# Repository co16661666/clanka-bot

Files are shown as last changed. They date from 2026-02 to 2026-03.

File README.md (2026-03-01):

# ⏰ deska clanka

An interactive, character-driven smart alarm clock built with the **Seeed Studio XIAO ESP32C3**. This project brings a standard clock to life using procedural OLED eye animations and coordinated servo-driven arms to express different moods based on the time of day or user interaction.

## ✨ Features
* **Procedural Eye Animations:** Uses geometric masking on an SSD1306 OLED to create smooth, expressive eyes without consuming excess memory with image files.
* **Coordinated Arm Movements:** Two micro-servos act as arms that react alongside the facial expressions.
* **Dynamic Moods:** Transitions seamlessly between states like Happy, Tired, Sleepy, Stretching, and an active Alarm sequence.
* **Custom Enclosure:** Physical housing and mounting brackets designed entirely in Solidworks.

---

## 🛠️ Hardware & CAD Design (Per Module)
* **Microcontroller:** [Seeed Studio XIAO ESP32C3](https://www.seeedstudio.com/Seeed-XIAO-ESP32C3-p-5431.html)
* **Display:** 0.96" I2C OLED Display (SSD1306)
* **Actuators:** 2x Micro Servos (e.g., SG90)
* **Power:** 3.3V supply (via power bank)

### Mechanical Design
The physical enclosure and servo mounts were modeled using **Solidworks**. 
* The CAD files (including native `.SLDPRT`/`.SLDASM` and `.STL` files for 3D printing, which are not included here) can be found in the `/housing` directory of this repository. Previous versions of the arm are still in the repository, with V2 files being the most up to date.
* The Arduino files were .ino and relate to the `/expressions-programV2` and `/brain-program` files in the repository.

---

## ⚙️ Setup and Installation

### 1. Wiring Guide
Ensure your components are wired exactly as follows before connecting power:

| Component | Pin Name | XIAO Pin (Label) | ESP32 GPIO |
| :--- | :--- | :--- | :--- |
| **OLED SDA** | SDA | D4 | GPIO 6 |
| **OLED SCL** | SCL | D5 | GPIO 7 |
| **Left Arm Servo** | Signal | D0 | GPIO 2 |
| **Right Arm Servo** | Signal | D1 | GPIO 3 |
| **All Components** | VCC | 3V3 | - |
| **All Components** | GND | GND | - |

### 2. Software Installation
This project is programmed using the Arduino IDE.
1. Download and install the [Arduino IDE](https://www.arduino.cc/en/software).
2. Add ESP32 Support: 
   * Go to **File > Preferences**.
   * Add `https://espressif.github.io/arduino-esp32/package_esp32_index.json` to the **Additional Boards Manager URLs**.
   * Go to **Tools > Board > Boards Manager**, search for `esp32` by Espressif Systems, and install it (Version 3.0.0 or higher required).
3. Select your board: Go to **Tools > Board > esp32** and select **XIAO_ESP32C3**.

### 3. Required Libraries
Open the Arduino Library Manager (**Sketch > Include Library > Manage Libraries...**) and install the following:
* `Adafruit_GFX` by Adafruit
* `Adafruit_SSD1306` by Adafruit
* `ESP32Servo` by Kevin Harrington (Standard `Servo.h` will not work on the ESP32 chip).

### 4. Uploading the Code
1. Connect the XIAO ESP32C3 to your computer via USB-C.
2. Select the correct COM port under **Tools > Port**.
3. Open the `expressions-programV2.ino` sketch.
4. Click the **Upload** arrow.

---

## 🤝 Attributions & Acknowledgments
This project was made possible by several excellent open-source tools, libraries, and community inspirations:
* **Adafruit Industries:** For the `Adafruit_GFX` and `Adafruit_SSD1306` libraries that drive the OLED display.
* **Kevin Harrington:** For the `ESP32Servo` library, allowing standard PWM servo control on the ESP32 architecture.
* **Espressif Systems & Seeed Studio:** For the ESP32 core board definitions and the XIAO hardware.
* **Design Inspiration:** The procedural masking logic for the eye expressions was heavily inspired by the "Vinny" robot eye designs and various open-source animated OLED eye projects found across the maker community. 
* **Solidworks:** Used for all 3D mechanical design, part modeling, and assembly testing.
* **AI & LLM policy:** Used to generate only code and execute ideas we had as a team.

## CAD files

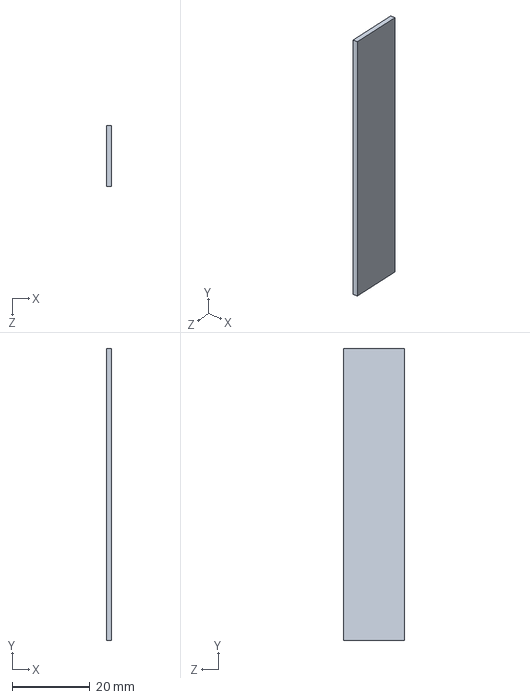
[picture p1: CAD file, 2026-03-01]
bot1/housing/solidwork_files/clanka_Arm1V2.SLDPRT
1.40 x 75.0 x 15.6 mm

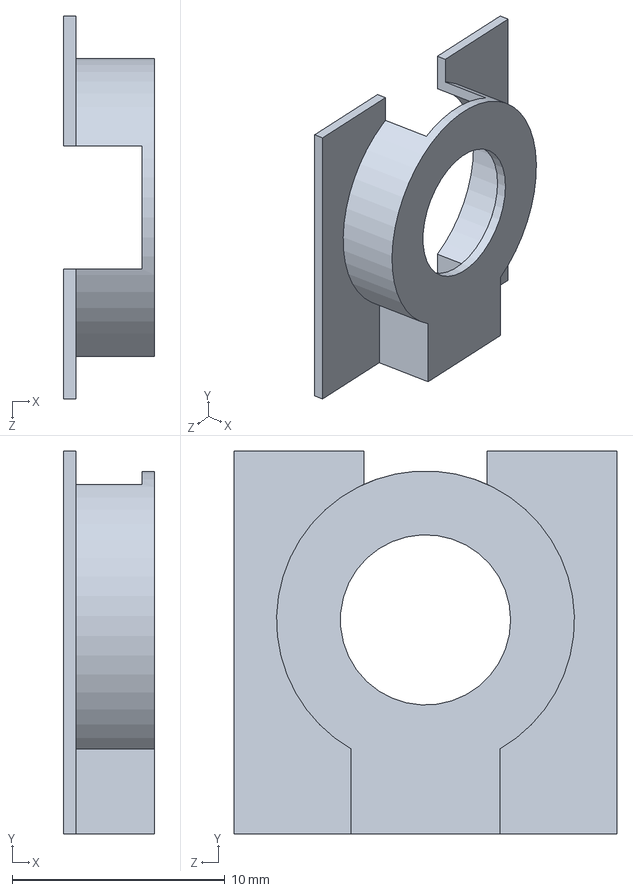
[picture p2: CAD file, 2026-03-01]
bot1/housing/solidwork_files/clankaBotArm_CasingV1.SLDPRT
4.30 x 18.0 x 18.0 mm

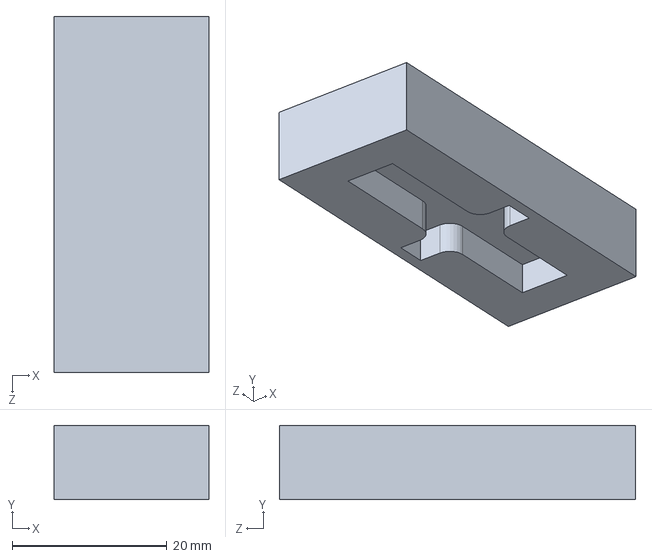
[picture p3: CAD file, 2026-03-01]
bot1/housing/solidwork_files/Arm_Connector_ClankaBotV2.SLDPRT
20.0 x 9.60 x 46.0 mm

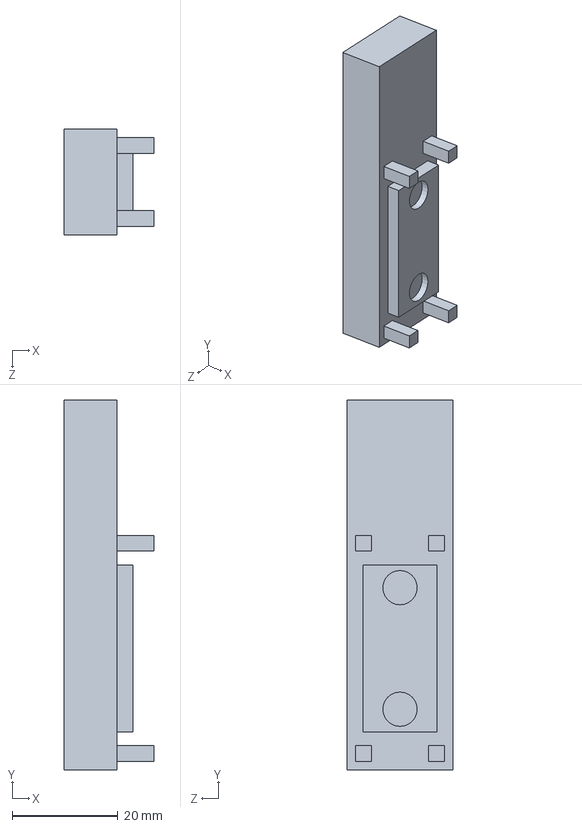
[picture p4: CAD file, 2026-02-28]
bot1/housing/solidwork_files/clanka_Arm1.SLDPRT
17.0 x 70.0 x 20.0 mm

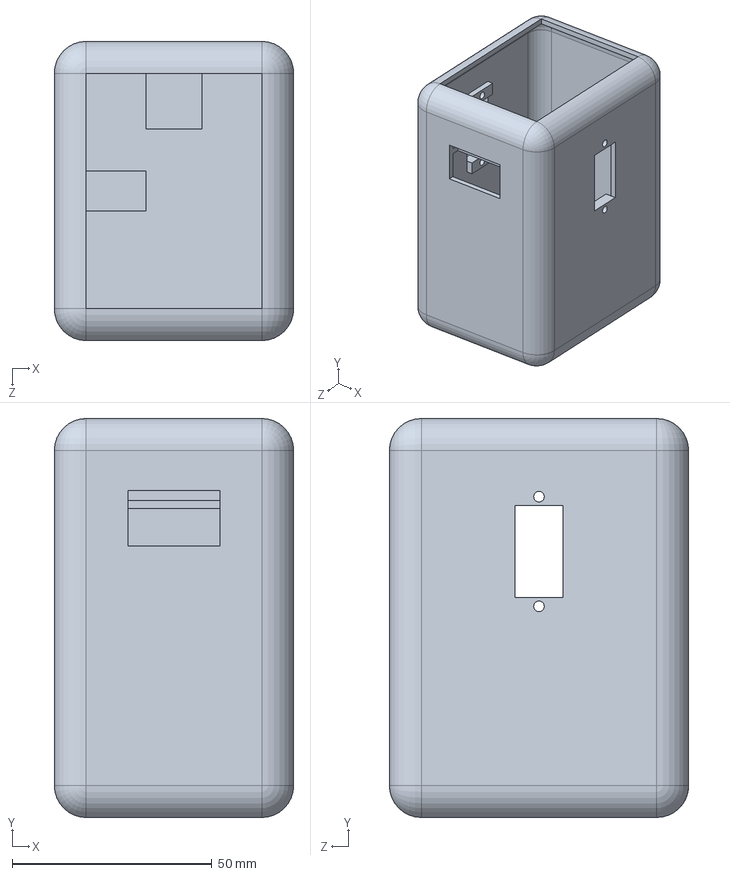
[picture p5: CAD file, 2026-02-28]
bot1/housing/solidwork_files/clanka_body.SLDPRT
60.0 x 100.0 x 75.0 mm

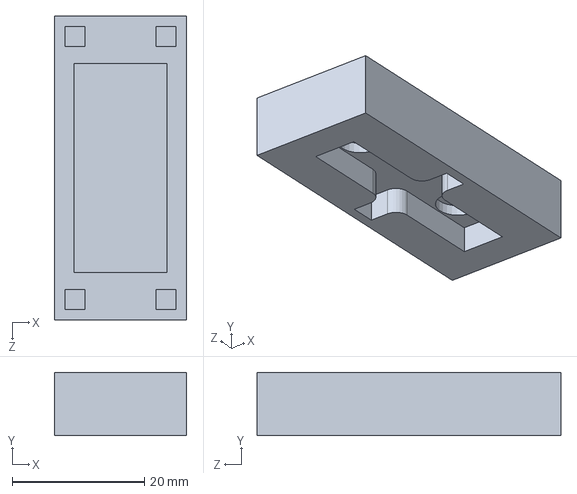
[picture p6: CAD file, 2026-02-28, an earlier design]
bot1/housing/solidwork_files/Arm_Connector_ClankaBotV1.SLDPRT
20.0 x 9.60 x 46.0 mm

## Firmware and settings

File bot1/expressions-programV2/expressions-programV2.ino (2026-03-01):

v#include <Wire.h>
#include <Adafruit_GFX.h>
#include <Adafruit_SSD1306.h>
#include <ESP32Servo.h> // Make sure to install "ESP32Servo" in the Library Manager!

// --- OLED SETTINGS ---
#define SCREEN_WIDTH 128
#define SCREEN_HEIGHT 64
#define OLED_RESET    -1 
Adafruit_SSD1306 display(SCREEN_WIDTH, SCREEN_HEIGHT, &Wire, OLED_RESET);

// XIAO ESP32C3 I2C Pins
#define I2C_SDA 6 
#define I2C_SCL 7 

// --- SERVO SETTINGS ---
Servo leftArm;
Servo rightArm;

// XIAO ESP32C3 Pins for Servos (D0 and D1)
const int leftArmPin = 2;  // Physical GPIO 2 corresponds to D0
const int rightArmPin = 3; // Physical GPIO 3 corresponds to D1

// --- MASTER EYE DRAWING FUNCTION ---
void drawVinnyEyes(int topEyelid, int bottomEyelid, int lookX) {
  display.clearDisplay();
  
  int eyeW = 24;
  int eyeH = 40;
  int leftX = 26;
  int rightX = 78; 
  int baseY = 12;

  // Draw the wide-open white eyes, shifted by lookX
  display.fillRoundRect(leftX + lookX, baseY, eyeW, eyeH, 8, SSD1306_WHITE);
  display.fillRoundRect(rightX + lookX, baseY, eyeW, eyeH, 8, SSD1306_WHITE);

  // Draw the Top Eyelid (Black box covering the top)
  if (topEyelid > 0) {
    display.fillRect(0, 0, 128, baseY + topEyelid, SSD1306_BLACK);
  }

  // Draw the Bottom Eyelid (Black box covering the bottom)
  if (bottomEyelid > 0) {
    display.fillRect(0, baseY + eyeH - bottomEyelid, 128, bottomEyelid + 15, SSD1306_BLACK);
  }

  display.display();
}

// ==========================================
// --- COMBINED MOOD FUNCTIONS ---
// ==========================================

void moodHappy() {
  drawVinnyEyes(0, 20, 0); // Joyful squint
  leftArm.write(90);       // Arms neutral
  rightArm.write(90);
}

void moodTired() {
  drawVinnyEyes(20, 0, 0); // Heavy top eyelids
  leftArm.write(45);       // Arms drooping down
  rightArm.write(135); 
}

void moodSleepy() {
  drawVinnyEyes(30, 0, 0); // Almost closed eyes
  leftArm.write(10);       // Arms fully resting
  rightArm.write(170); 
}

void moodSnoring() {
  drawVinnyEyes(18, 18, 0); // Squished flat lines
  
  // Add floating 'Zzz'
  display.setTextSize(1);
  display.setTextColor(SSD1306_WHITE);
  display.setCursor(55, 0);
  display.print("Z");
  display.setCursor(65, 8);
  display.print("z");
  display.display();
  
  leftArm.write(10);       // Arms resting
  rightArm.write(170);
}

void moodStretching() {
  // Eyes look left, arms go up
  drawVinnyEyes(0, 0, -8); 
  leftArm.write(150);  
  rightArm.write(30);  
  delay(600);
  
  // Eyes look right, arms wiggle
  drawVinnyEyes(0, 0, 8);  
  leftArm.write(120);
  rightArm.write(60);
  delay(300);
  
  // Eyes center, stretch finishes
  drawVinnyEyes(0, 0, 0);
  leftArm.write(150);
  rightArm.write(30);
  delay(600);
}

void moodAlarm() {
  // Wide open eyes, frantic arms
  drawVinnyEyes(0, 0, 0);
  leftArm.write(180);
  rightArm.write(0);
  
  display.invertDisplay(true); // Flash screen white
  delay(150);
  
  leftArm.write(0);
  rightArm.write(180);
  
  display.invertDisplay(false); // Flash screen back to normal
  delay(150);
}

// ==========================================
// --- REQUIRED ARDUINO FUNCTIONS ---
// ==========================================

void setup() {
  Serial.begin(115200);

  // 1. Setup Servos
  // We use ESP32Servo library standard attach
  leftArm.attach(leftArmPin);
  rightArm.attach(rightArmPin);

  // 2. Setup OLED with custom XIAO pins
  Wire.begin(I2C_SDA, I2C_SCL);
  if(!display.begin(SSD1306_SWITCHCAPVCC, 0x3C)) { 
    Serial.println(F("SSD1306 allocation failed"));
    for(;;); // Loop forever if display fails
  }
  
  display.clearDisplay();
  display.display();
}

void loop() {
  // A simple test sequence to cycle through all your moods!
  
  moodHappy();
  delay(3000);
  
  moodTired();
  delay(3000);
  
  moodSleepy();
  delay(3000);
  
  moodSnoring();
  delay(3000);
  
  moodStretching();
  delay(1000);
  
  // Flash the alarm a few times
  for(int i = 0; i < 10; i++) {
    moodAlarm();
  }
}

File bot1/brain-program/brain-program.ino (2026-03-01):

#include "arduino_secrets.h"
#include <WiFiClientSecure.h>
#include <MQTTClient.h>
#include <ArduinoJson.h>
#include "WiFi.h"
#include "vinny_moods.h"

// The MQTT topics that this device should publish/subscribe
#define AWS_IOT_PUBLISH_TOPIC   "esp32/pub"
#define AWS_IOT_SUBSCRIBE_TOPIC "esp32/sub"

WiFiClientSecure net = WiFiClientSecure();
MQTTClient client = MQTTClient(256);

void connectAWS()
{
  WiFi.mode(WIFI_STA);
  WiFi.begin(WIFI_SSID, WIFI_PASSWORD);

  Serial.println("Connecting to Wi-Fi");

  while (WiFi.status() != WL_CONNECTED){
    delay(500);
    Serial.print(".");
  }

  // Configure WiFiClientSecure to use the AWS IoT device credentials
  net.setCACert(AWS_CERT_CA);
  net.setCertificate(AWS_CERT_CRT);
  net.setPrivateKey(AWS_CERT_PRIVATE);

  // Connect to the MQTT broker on the AWS endpoint we defined earlier
  client.begin(AWS_IOT_ENDPOINT, 8883, net);

  // Create a message handler
  client.onMessage(messageHandler);

  Serial.print("Connecting to AWS IOT");
  
  while (!client.connect(THINGNAME)) {
    Serial.print(".");
    
    // Print diagnostic information
    Serial.println();
    Serial.print("MQTT Error Code: ");
    Serial.println(client.lastError());
    Serial.print("MQTT Return Code: ");
    Serial.println(client.returnCode());
    
    delay(1000);
  }

  if(!client.connected()){
    Serial.println("AWS IoT Timeout!");
    return;
  }

  // Subscribe to a topic
  client.subscribe(AWS_IOT_SUBSCRIBE_TOPIC);

  Serial.println("AWS IoT Connected!");
}

void publishMessage()
{
  StaticJsonDocument<200> doc;
  doc["time"] = millis();
  doc["sensor_a0"] = analogRead(0);
  char jsonBuffer[512];
  serializeJson(doc, jsonBuffer); // print to client

  if (client.publish(AWS_IOT_PUBLISH_TOPIC, jsonBuffer)) {
    Serial.println("Publish Success");
  } else {
    Serial.println("Publish Failed");
  }
}

void messageHandler(String &topic, String &payload) {
  Serial.println("incoming: " + topic + " - " + payload);

  StaticJsonDocument<200> doc;
  deserializeJson(doc, payload);
  const char* message = doc["message"];
}

void setup() {
  Serial.begin(9600);
  connectAWS();
}

void loop() {
  publishMessage();
  client.loop();
  delay(1000);
}

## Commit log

2026-02-28 added error logging in serial monitor and renamed arduino secrets file
    [brain-program.ino]
2026-02-28 initial clanka housing
    [clanka_body.SLDPRT]
2026-02-28 Added 2 Arm components, will push the final arm soon
    [Arm_Connector_ClankaBotV1.SLDPRT, clankaBotArm_CasingV1.SLDPRT]
2026-02-28 added final arm for magnet assem, also added an alternative arm too
    [Arm_Connector_ClankaBotV2.SLDPRT, clanka_Arm1.SLDPRT, clanka_Arm1V2.SLDPRT]
2026-03-01 All the final parts of the Arm are added
    [Arm_Connector_ClankaBotV2.SLDPRT, clankaBotArm_CasingV1.SLDPRT, clanka_Arm1V2.SLDPRT]
2026-03-01 Initial Commit of arm and expressions code
